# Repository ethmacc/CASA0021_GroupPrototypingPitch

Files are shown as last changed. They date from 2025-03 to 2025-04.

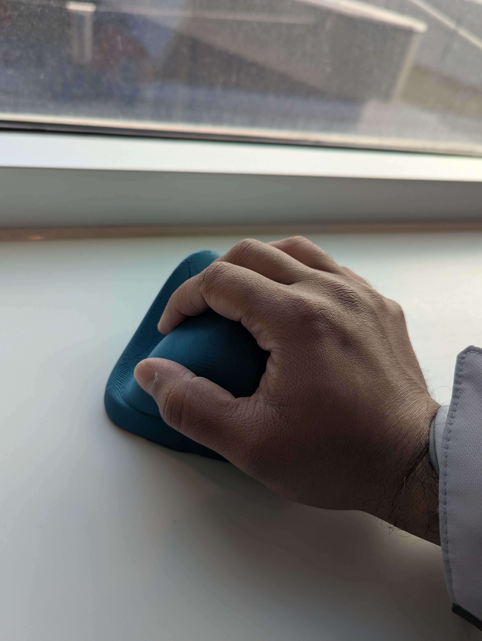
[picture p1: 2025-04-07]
Media/blue_test_form_4.jpg

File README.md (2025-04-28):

# HotStone - a CASA0021: Group Prototype and Pitch project



*Share the healing sense of touch with loved ones, from anywhere.*

## Table of Contents

- [What is HotStone?](#what-is-hotstone)
- [Getting Started](#getting-started)
    - [Setup](#setup)
    - [Libraries](#libraries-used)
    - [Running the App](#running-the-application)
- [Physical Build](#physical-build)
    - [Materials](#materials)
    - [Enclosure](#enclosure)
    - [Circuit](#circuit)
- [Future Updates](#future-updates)
- [Further Questions](#Further-Questions)
- [Developers](#developers)

## What is HotStone?



HotStone is a prototype device that allows two users to bond over a shared experience of warmth across the distance. It is primarily aimed at users who, for one reason or another, find themselves in a long-distance relationship / friendship with another person or family member. Utilizing Internet-of-Things (IoT) technology, it is possible to create an interaction where one user putting their hand on their device creates a warm sensation for the other person when they touch the other paired device and vice versa.

There have been a number of attempts to create devices that connect people over the miles, such as [Frebble by Frederic Petrignani](https://www.kickstarter.com/projects/396691740/hold-hands-online-when-you-miss-someone). However, we believe we are the first to successfully demonstrate a prototype device that is able to transfer warmth to another user over the internet.

Demo video (Youtube link):

project HotStone Video (https://www.youtube.com/watch?v=c_PSqZbkBAk)

## Getting Started

### Setup
To reproduce this project, users will need to first set up [PlatformIO on VS Code](https://platformio.org/install/ide?install=vscode). Once the user has the software directory on their local machine, and opened on PlatformIO, the register, and calibration process can begin. Within the `include` directory, create a file named `macAddr.h` this file can maintain the unique MAC addresses of the partner devices, as well as the unique threshold value for the capacitive sensor. This file will require the following format:
```
#pragma once

#include <stdint.h>

#define DEVICE_B

#ifdef DEVICE_A   // Device B Address
   static const uint8_t MAC_ADDR_LIST[] = {0x01, 0x02, 0x03, 0x04, 0x05, 0x06};
   static const uint8_t DEVICE_THRESHOLD = xxx;

#endif
#ifdef DEVICE_B   // Device A Address
   static const uint8_t MAC_ADDR_LIST[] = {0x07, 0x08, 0x09, 0x10, 0x11, 0x12};
   static const uint8_t DEVICE_THRESHOLD = xxx;
#endif

```

For each device the user will need to find their unique MAC Address and replace the values within the above arrays. This can be done by running using the following script on your device:

```
uint8_t baseMac[6];
esp_err_t ret = esp_wifi_get_mac(WIFI_IF_STA, baseMac);
if (ret == ESP_OK) {
  Serial.printf("%02x:%02x:%02x:%02x:%02x:%02x\n",
                baseMac[0], baseMac[1], baseMac[2],
                baseMac[3], baseMac[4], baseMac[5]);
} else {
  Serial.println("Failed to read MAC address");
}
``` 

Once the MAC addresses have been set, we can set the threshold values. With the device plugged into a computer, open the serial port monitor, and place your hand on the device. The serial port should print out the capacitive values. Select a sensible value between the capacitive values when the hand is not on the device, as opposed to the values after the hand has been placed on the device. This value will replace the `xxx` within the `macAddr.h` file. With this code flashed on both devices, the user is ready to use the device normally.

### Libraries Used

- [Adafruit NeoPixel](https://docs.arduino.cc/libraries/adafruit-neopixel/): to Adjust colors
- [Capacitive Sensor](https://docs.arduino.cc/libraries/capacitivesensor/): to Register a Users Touch

### Running the Application

Once the user has saved the MAC Address and capacitive touch threshold value, flash the code to the microcontroller in PlatformIO.

## Physical build

### Materials

You will need the following materials for this build:
- A 3D printer and filament
- Protoboard or stripboard for the circuit prototype build
- Wire
- FQP30N06L MOSFET
- 220K Ohm resistor
- Aluminium foil
- 8-LED Neopixel LED strip
- USB male cable
- Node MCU
- Pin headers (male and female)
- Heating pads, available on Amazon from multiple sources

### Enclosure



The 3D models for the enclosure can be found in ```Modeling/3D_models```. Use these to print out a copy of the enclosure to house the electronics in. We recommend printing the top shell of the enclosure in a solid material and the bottom part in translucent to allow the LED light to diffuse out.

You can adapt the 3D models to fit any protoboard size and configuration, but for the easiest solution, we recommend taking dimensions from the dummy protoboard in the 3D model files.

### Circuit

The circuit diagram for the device is shown below:

thumbnail_image (1)

As well as the schematic for the layout of the protoboard:

thumbnail_image

Using these, it is possible to reconstruct the arrangement shown below, by soldering the heating pads, header pins for the Node MCU and the MOSFET transistor to the protoboard:





Power is supplied to the device using the USB cable, stripped and connected to the relevant power in and ground pins of the Node MCU (the thick wire leading out to the right):



The Neopixel strip is not soldered on but rather attached to a fixed position facing up and connected to the circuit via wire jacks and pin headers.

Note that the IMU was replaced by a capative sensor for a more natural human interaction, using the [Capacitive Sensor arduino library](https://docs.arduino.cc/libraries/capacitivesensor/).

The main code in ```software/hotstone/src/main.cpp``` describes which pins the capacitive sensor should be soldered to. A 220k Ohm resistor was used for this sub-circuit (tested with an ESP8266) and aluminium foil was used for the sesnor plate, but these can be adjusted to your liking:



More information on capacitive sensor circuits can be found on the web, such as [this Instructables link](https://www.instructables.com/How-To-Use-Touch-Sensors-With-Arduino/).

## Future Updates

- Further study into material selection
- Further study into NiChrome Wire as a heating element
- Convert prototype board to PCB
- Convert ESP-NOW to WiFi
- Add QR Code or NFC tag to link users to a page to add WiFi details or add multiple devices to the network

## Further Questions

Please reach out to the developers of this project, or add an issue to this repo.

## Developers
<a href="https://github.com/ethmacc/CASA0021_GroupPrototypingPitch/graphs/contributors">
  
</a>

### Prototype and Software
Vineeth Kirandumkara: [@vineethk96](https://github.com/vineethk96)

### Product Design
Ethan Low: [@ethmacc](https://github.com/ethmacc)

### PCB Design
Donghao Zhang: [@wudaozhiying1](https://github.com/wudaozhiying1)

### Media
Yue Zhu: [@XLunaXX07](https://github.com/XLunaXX07)

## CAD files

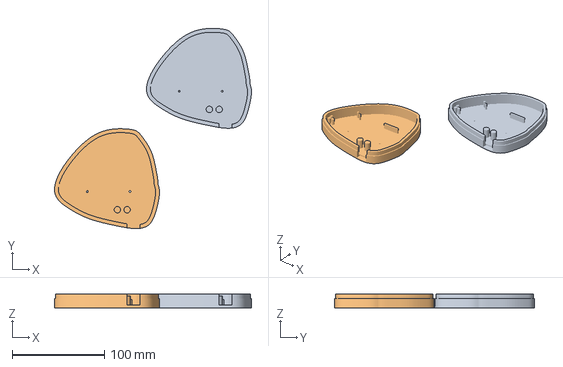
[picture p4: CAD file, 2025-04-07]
Modeling/3D_models/Enclosure/form_final_revised_base.3mf
213.1 x 216.6 x 15.0 mm
form_final_revised_base.stl x 2

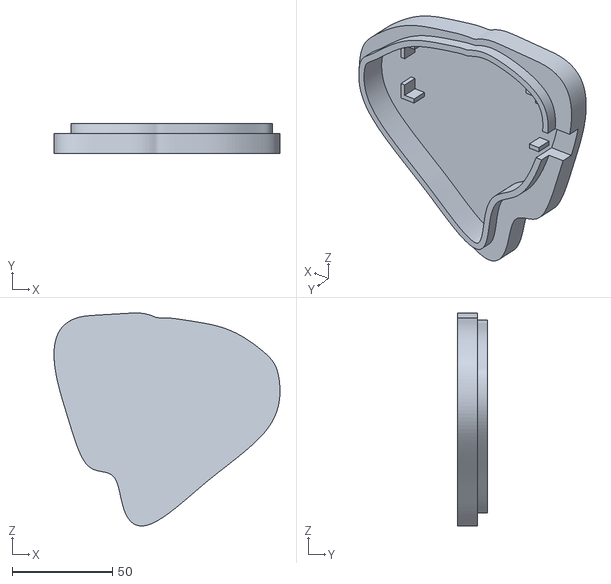
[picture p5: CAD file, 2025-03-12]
Modeling/3D_models/Enclosure/superseeded/form_reduced_base.stl
112.9 x 15.0 x 106.4

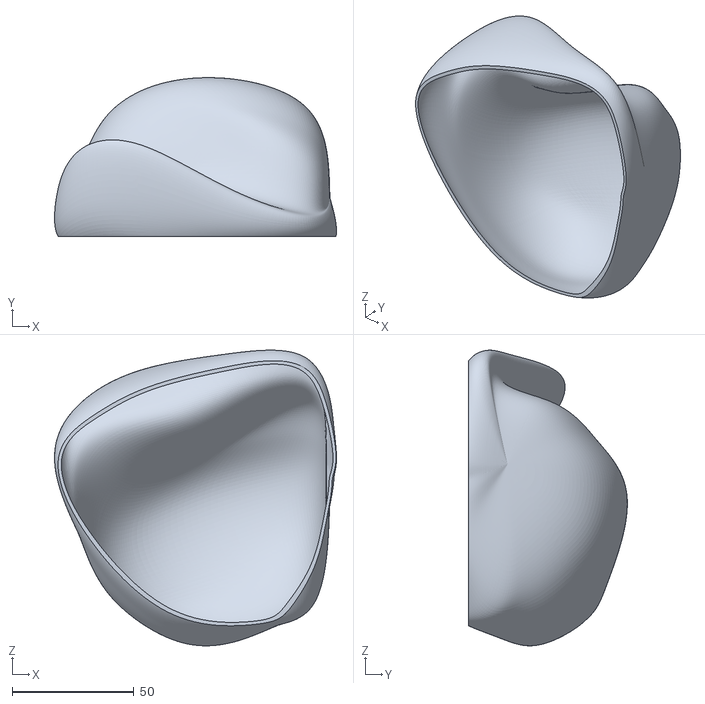
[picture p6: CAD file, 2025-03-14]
Modeling/3D_models/Enclosure/form_1_5mm_final.stl
115.8 x 65.2 x 121.4

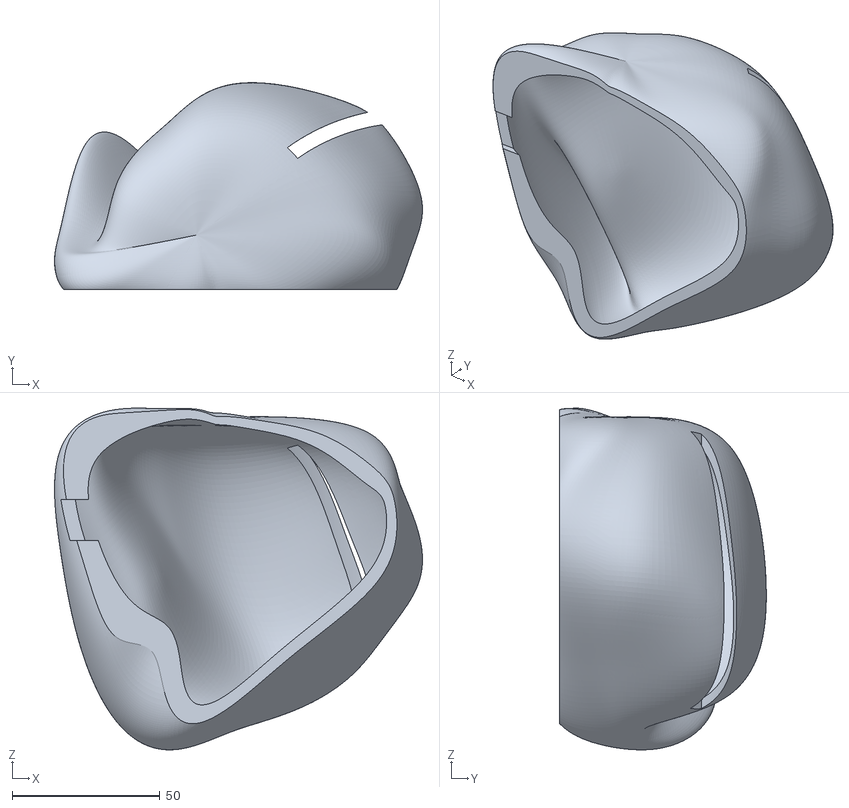
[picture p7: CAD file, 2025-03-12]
Modeling/3D_models/Enclosure/superseeded/form_reduced_top.stl
124.6 x 70.0 x 115.7

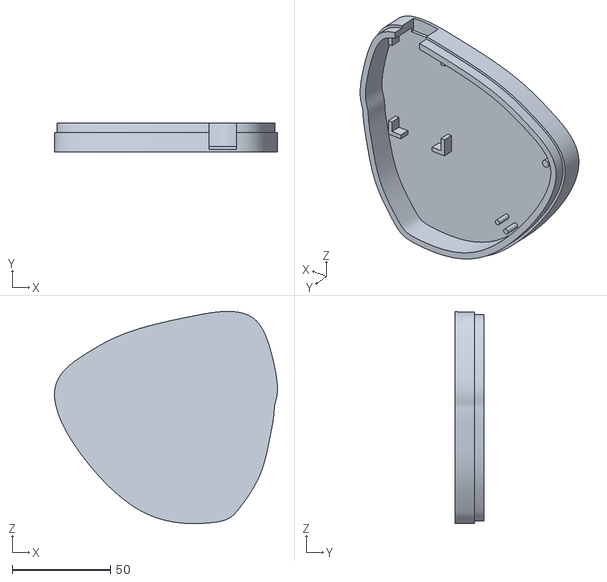
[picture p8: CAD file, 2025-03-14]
Modeling/3D_models/Enclosure/base_final.stl
113.6 x 15.0 x 108.1

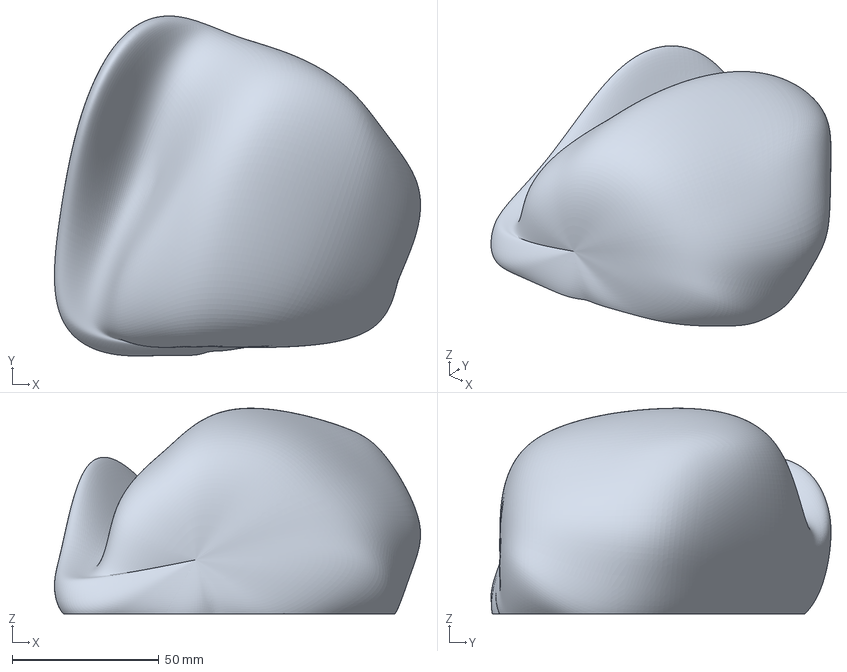
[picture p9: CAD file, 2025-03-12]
Modeling/3D_models/Enclosure/superseeded/form_reduced_top_channel.3mf
124.6 x 115.7 x 70.0 mm

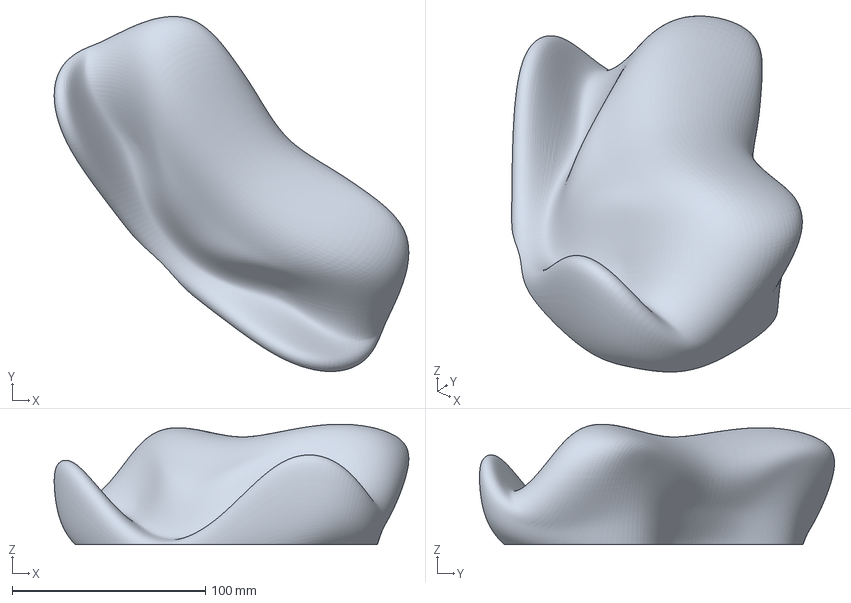
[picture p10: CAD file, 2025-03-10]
Modeling/3D_models/Enclosure/superseeded/form_test.3mf
183.3 x 183.5 x 62.2 mm

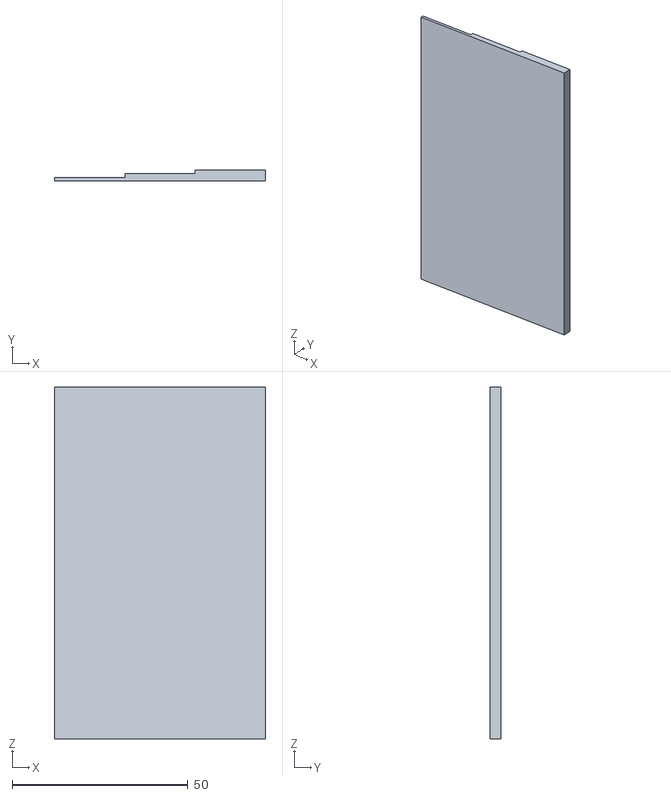
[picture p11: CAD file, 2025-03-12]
Modeling/3D_models/Enclosure/thickness test v2.stl
60.0 x 3.00 x 100.0

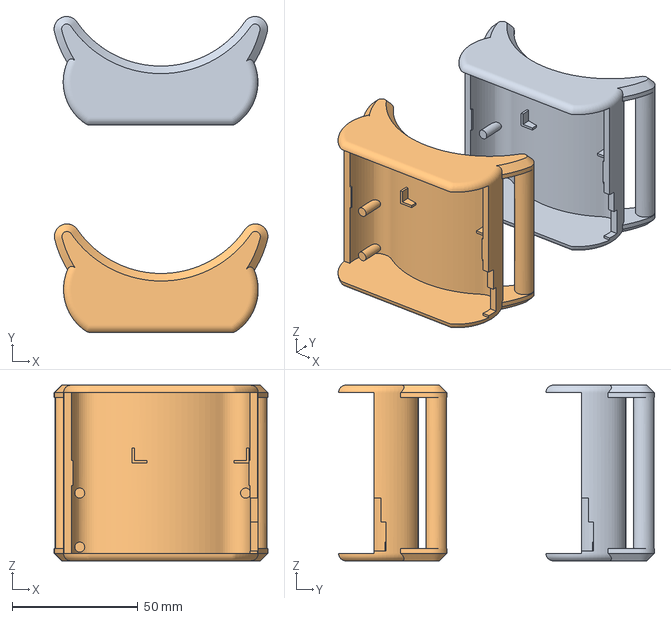
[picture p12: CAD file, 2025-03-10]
Modeling/3D_models/Enclosure/superseeded/MugSleeve v12.3mf
85.1 x 125.8 x 70.0 mm
MugSleeve _backcover.stl x 2

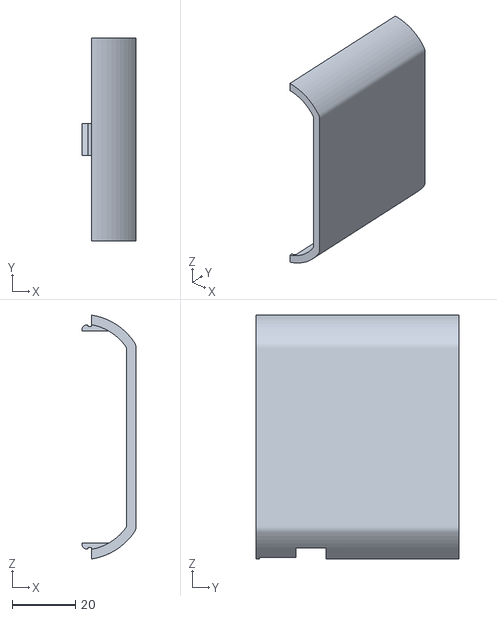
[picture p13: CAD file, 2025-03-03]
Modeling/3D_models/Enclosure/superseeded/MugSleeve_v12_frontcover.stl
17.1 x 64.0 x 77.1

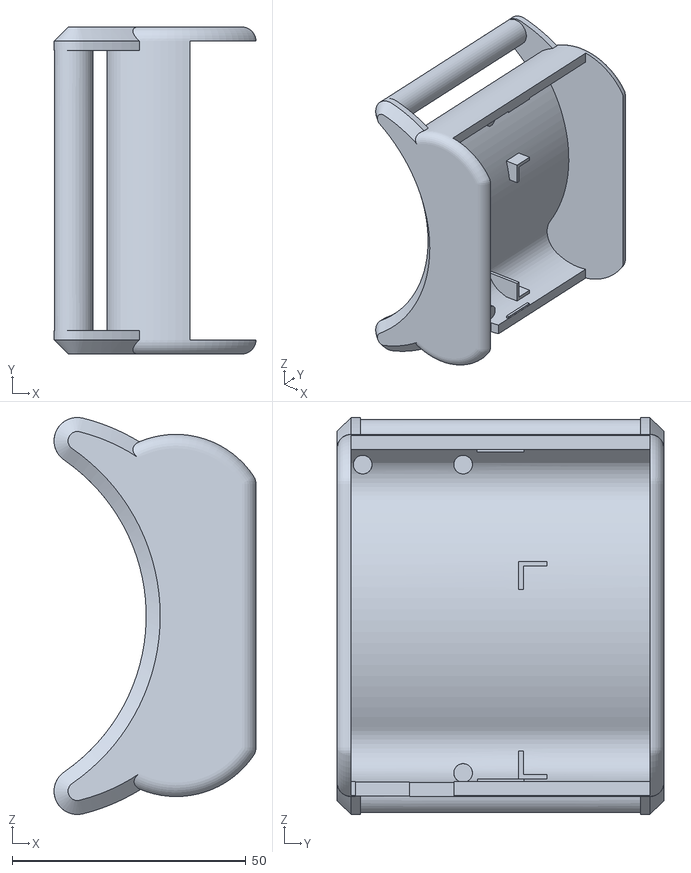
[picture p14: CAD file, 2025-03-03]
Modeling/3D_models/Enclosure/superseeded/MugSleeve _backcover.stl
43.2 x 70.0 x 85.0

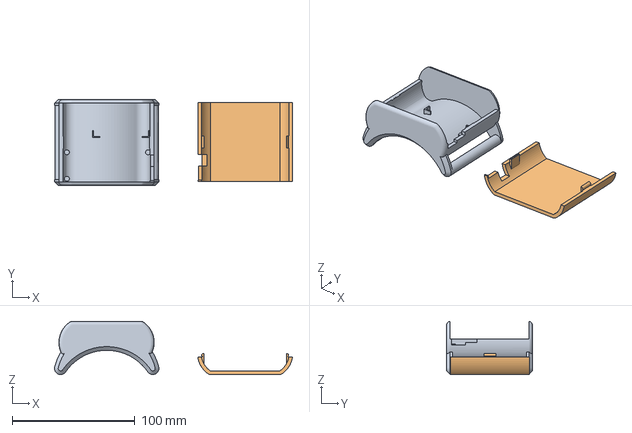
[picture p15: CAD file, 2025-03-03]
Modeling/3D_models/Enclosure/superseeded/MugSleeve_testprint.3mf
193.7 x 70.0 x 43.2 mm
MugSleeve v12.stl
MugSleeve_v12_frontcover.stl

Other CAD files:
Modeling/3D_models/Enclosure/form_final_revised_base.stl
Modeling/3D_models/Enclosure/superseeded/MugSleeve v12.stl
Modeling/3D_models/Enclosure/superseeded/MugSleeve v13_backcover.f3d
Modeling/3D_models/Enclosure/superseeded/form_reduced_top_channel.stl
Modeling/3D_models/Enclosure/superseeded/form_test.stl

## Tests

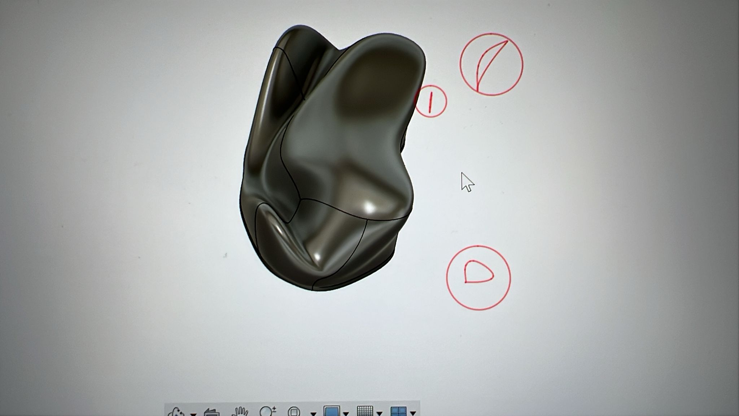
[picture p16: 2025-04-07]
Media/maroon_test_form_model_1.jpeg

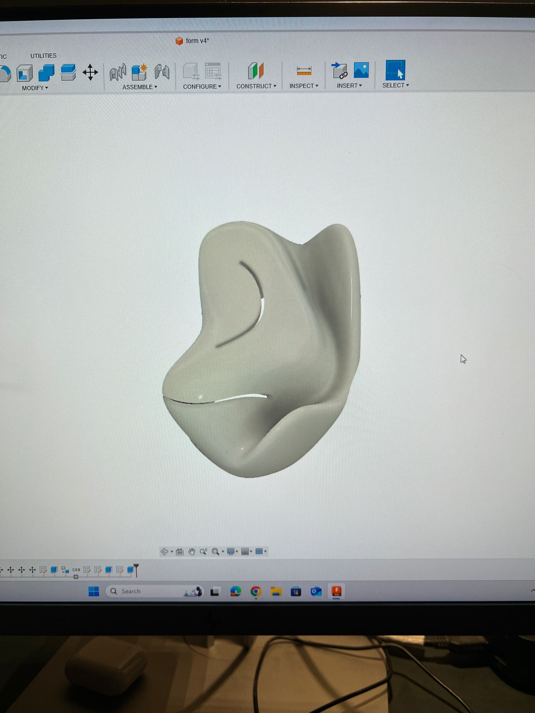
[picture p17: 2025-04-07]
Media/maroon_test_form_model_3.jpeg

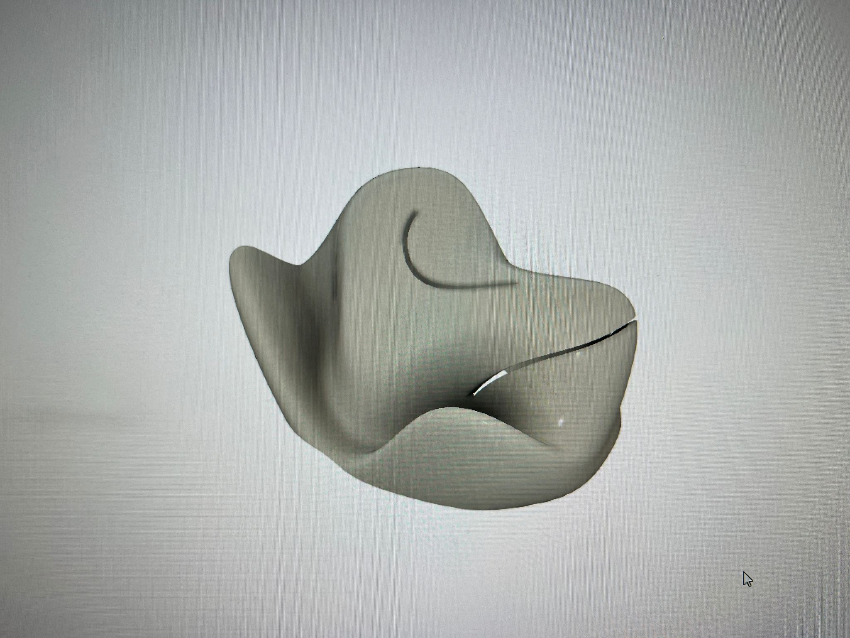
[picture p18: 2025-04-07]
Media/maroon_test_form_model_2.jpeg

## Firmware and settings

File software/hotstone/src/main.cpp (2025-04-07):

#include <Arduino.h>
#include <ESP8266WiFi.h>
#include <Adafruit_NeoPixel.h>
#include <espnow.h>
#include <string.h>
#include "touchSensor.hpp"
#include "macAddr.h"

// GPIOs
// #define LED_BUILTIN D0  // defined within Arduino.h
#define HEATING_COIL D3
#define NEOPIXEL D4
#define CATHODE D8
#define ANODE D5

// Time Constants
#define ONE_SEC 1000
#define FIVE_MIN 20000

// NeoPixel Constants
#define NUMPIXEL_COUNT 8
#define R_HEX 255
#define G_HEX 169
#define B_HEX 87
#define W_HEX 255

#define PULSE_RATE 1
#define MAX_PULSE_BRIGHTNESS 255

// Touch Sensor
touchSensor touch(CATHODE, ANODE, DEVICE_THRESHOLD);

// NeoPixel
Adafruit_NeoPixel baseLight = Adafruit_NeoPixel(NUMPIXEL_COUNT, NEOPIXEL, NEO_GRB + NEO_KHZ800);

// Buddy Address
uint8_t buddyAddress[sizeof(MAC_ADDR_LIST)] = {0};  // Ensure the size matches LIST

// Check if the device is on
bool isOn = false;

// Heating Element
unsigned long heat_timestamp = 0;

// Message Structure
typedef struct msg_type{
  bool isMoving;
}msg_t;

// Callback Functions
void OnDataSent(uint8_t *mac_addr, uint8_t sendStatus);
void OnDataRecv(uint8_t *mac_addr, uint8_t *data, uint8_t len);

// Lighting Effect Functions
void pulseLight(void);

/**
 * @brief Callback function that will be called when data is sent
 * 
 * @param mac_addr MAC address of the recipient
 * @param sendStatus Status of the data send
 * @return void
 */
void OnDataSent(uint8_t *mac_addr, uint8_t sendStatus) {

  // Serial.print("Msg Sent to: ");
  // for (int i = 0; i < 6; i++) {
  //   Serial.print(mac_addr[i], HEX);
  //   if (i < 5){
  //     Serial.print(":");
  //   }
  // }
  // Serial.println();

  Serial.print("Last Packet Send Status: ");
  if (sendStatus == 0){
    Serial.println("Delivery success");
  }
  else{
    Serial.println("Delivery fail");
  }
}

/**
 * @brief Callback function that will be called when data is received
 * 
 * @param mac_addr MAC address of the sender
 * @param incomingData Data received
 * @param len Length of the data received
 * @return void
 */
void OnDataRecv(uint8_t *mac_addr, uint8_t *data, uint8_t len) {

  msg_t newMsg;
  memcpy(&newMsg, data, sizeof(newMsg));
  // Serial.print("Msg Received: ");
  // Serial.println(len);
  // Serial.print("isMoving: ");
  // Serial.println(newMsg.isMoving);
  // Serial.println();

  // Begin the heating, and note that the partner is active
  heat_timestamp = millis();
  isOn = true;

  // Turn on Heating
  digitalWrite(HEATING_COIL, HIGH);
}

/**
 * @brief Function to pulse the light
 */
void pulseLight(void)
{

  static uint8_t brightness = 0;
  static bool glowUp;

  // Check if glow up or down needs to change
  if(brightness >= MAX_PULSE_BRIGHTNESS){
    glowUp = false;
  }
  else if(brightness <= 0){
    glowUp = true;
  }

  // Update the brightness
  if(glowUp){
    brightness += PULSE_RATE;
  }
  else{
    brightness -= PULSE_RATE;
  }

  // DO NOT DELETE: for some reason, this slows the pulse rate enough to be a nice soft pulse.
  Serial.print("Brightness: ");
  Serial.println(brightness);

  // Set the brightness
  for(uint8_t i = 0 ; i < NUMPIXEL_COUNT; i++){
    baseLight.setPixelColor(i, baseLight.Color(R_HEX, G_HEX, B_HEX, W_HEX));
  }
  baseLight.setBrightness(brightness);
  baseLight.show();  
}

void setup() {

  // Configure board LED pin for output
  pinMode(LED_BUILTIN, OUTPUT);

  // Blink to test power on: Something seems fishy on startup
  digitalWrite(LED_BUILTIN, HIGH);
  delay(1000);
  digitalWrite(LED_BUILTIN, LOW);

  // Initialize Serial Monitor
  Serial.begin(9600);
  while (!Serial)
    delay(10); // will pause Zero, Leonardo, etc until serial console opens

  delay(1000);

  Serial.println("Starting...");

  // Configure Heating Coil MOSFET pin for output
  pinMode(HEATING_COIL, OUTPUT);

  // Set GPIOs to OFF
  digitalWrite(LED_BUILTIN, LOW);  // Start LED off as low
  digitalWrite(HEATING_COIL, LOW);  // Start Heating Coil off as low

  // Initialize the NeoPixel
  baseLight.begin();
  for(uint8_t i = 0 ; i < NUMPIXEL_COUNT; i++){
    baseLight.setPixelColor(i, baseLight.Color(R_HEX, G_HEX, B_HEX, W_HEX));
  }
  baseLight.setBrightness(0); // Set the brightness to 0
  baseLight.show();

  // Import the buddy address from the header file
  memcpy(buddyAddress, MAC_ADDR_LIST, sizeof(MAC_ADDR_LIST));

  // Announce the buddy address
  Serial.println("This is my buddy: ");
  for (int i = 0; i < 6; i++) {
    Serial.print(buddyAddress[i], HEX);
    if (i < 5){
      Serial.print(":");
    }
  }

  // Set the device as a WIFI Station
  WiFi.mode(WIFI_STA);
  Serial.println("Set as WiFi Station");

  // Init ESP-NOW
  if (esp_now_init() != 0) {
    Serial.println("Error initializing ESP-NOW");
    return;
  }
  Serial.println("ESP-NOW Initialized");

  // Set device as a combo
  esp_now_set_self_role(ESP_NOW_ROLE_COMBO);
  Serial.println("Set as Combo");

  // Register callback functions
  esp_now_register_send_cb(OnDataSent);
  esp_now_register_recv_cb(OnDataRecv);
  Serial.println("Registered Callbacks");

  // Add broadcast address
  esp_now_add_peer(buddyAddress, ESP_NOW_ROLE_COMBO, 1, NULL, 0);
  Serial.println("Added Buddy");

  delay(1000);
}

void loop() {

  static unsigned long poll_timestamp = millis();

  // Update at Loop Speed
  if(isOn){
    pulseLight();
  }
  else{
    baseLight.setBrightness(0);
    baseLight.show();
  }

  // Update every Second
  if(millis() - poll_timestamp > ONE_SEC){

    if(touch.checkTouch()){
      Serial.println("Touch Detected.");

      heat_timestamp = millis();
      isOn = true;

      // Send a message 
      msg_t newMsg;
      newMsg.isMoving = true;
      Serial.println("Message Sending.");
      esp_now_send(buddyAddress, (uint8_t *) &newMsg, sizeof(newMsg));
    }
    else{
      Serial.println("No Touch Detected.");
    }

    poll_timestamp = millis();
  }

  // Safety Condition to prevent heating over 5 min
  if(isOn){

    // Check if we should reset
    if(millis() - heat_timestamp > FIVE_MIN){
      Serial.println("Heating Complete");
      digitalWrite(HEATING_COIL, LOW);

      isOn = false;
    }
  }
}

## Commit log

2025-02-12 Add files via upload
    PCB with acceleration sensor MPU-6050,without speaker and pressure sensor
2025-02-12 First verson with speaker and pressure sensor
2025-02-19 V3 with charge chip
2025-03-03 Add 3D print files
    [MugSleeve v12.stl, MugSleeve_testprint.3mf, MugSleeve_v12_frontcover.stl]
2025-03-04 ongoing: talking to nodeMCU is a success. The Adafruit_MPU6050 library doesn't work with the current hardware, so need to change that, and setup the original MPU library
    [main.cpp]
2025-03-04 chore: working through imu library with rolling averages, negative numbers are giving me issues
    [main.cpp]
2025-03-04 chore: IMU library works. It detects movement very quickly
2025-03-05 feat: cleaned up the IMU Library, ready for comms
2025-03-05 feat: two devices can talk when motion is detected
2025-03-05 chore: added more print statements, but this seems to be working
2025-03-10 Add form tests
    [MugSleeve _backcover.stl, MugSleeve v12.3mf, MugSleeve v12.stl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]
2025-03-12 Add updated form models
    [MugSleeve _backcover.stl, MugSleeve v12.3mf, MugSleeve v12.stl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]
2025-03-12 Add thickness test model
    [thickness test v2.stl]
2025-03-13 chore: missed some update lines
    [main.cpp]
2025-03-14 Add final models for ABS print
    [base_final.stl, form_1_5mm_final.stl, form_reduced_top.stl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]
2025-03-14 chore: adjusted some tabbing issues
    [main.cpp]
2025-03-14 chore: each IMU is unique, therefore, the algo needs to be changed based on positive and negative values. This is something to take into account and fix within the software. Also, Device A can talk a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
    [main.cpp]
2025-03-18 chore: issues occured with the imu readings, we've switched to using a capacitive touch sensor. Furthermore, there are possible issues with the Device B MCU
    [main.cpp]
2025-03-18 feat: switched from using the imu to the capactive touch sensor. Moved the code to a library, and using a moving average algo to smooth out any spontaneous spikes in readings. Note: a touch through t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
2025-03-18 feat: switched to using a threshold, instead of rolling avg
2025-03-19 feat: fixed the solo lighting bug. Note: there is a weird bug associated with printing the brightness print statements.
    [main.cpp]
2025-03-20 chore: cleaning up the repo file structure
    [MugSleeve _backcover.stl, MugSleeve v12.3mf, MugSleeve v12.stl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]
2025-04-07 Add updated renders
    [form_final_revised_base.3mf, form_final_revised_base.stl]
